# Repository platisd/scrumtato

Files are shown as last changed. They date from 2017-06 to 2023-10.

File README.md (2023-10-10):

# Scrumtato
Scrumtato is an ATtiny85-based gadget to keep overly passionate developers from excessively talking during daily stand-up meetings. The name stems from the combination of [SCRUM](https://en.wikipedia.org/wiki/Scrum_(software_development)) and [Hot Potato](https://en.wikipedia.org/wiki/Hot_potato_(game)).

## About Scrumtato
During our daily stand-up meetings (SCRUM), as we are a team full of talented and passionate developers, we just love to talk too much. This stretches our meeting and keeps us from getting the most out of our working hours. To solve this problem, here comes **Scrumtato: A gadget to make daily stand-ups agile again!**

scrumtatos

## How does it work
Operating the Scrumtato is simple!
1. Press the button when you are ready to talk. You will hear 2 beeps.
2. Start talking. You have to concisely explain what you did since the last meeting and what you are planning to do until the next.
3. If you finish before the time runs out (in which case the Scrumtato will beep and vibrate), press the button again. You will hear 3 beeps.

### More details
The user begins interacting with the Scrumtato by pressing the on-board button and starts talking about all the extraordinary things they got into since the last daily stand-up. This initiates a countdown timer that lasts as long as each team member is supposed to speak. To indicate that half of the remaining time has just been depleted, Scrumtato will beep once. For example, if the total available period for someone to speak is 1 minute, the user will hear beeps on approximately the 30th, 45th, 52nd, 56th, 58th and 59th seconds. As soon as the time is up, a characteristic beep sequence is played and Scrumato vibrates.

In other words, Scrumtato can be considered as a stress ball that... actually stresses you out! If the team member finishes talking in a timely manner, then they merely need to press the button again and a sound sequence that indicates the successful end of a turn is played.

From a technical perspective, since the users should not have to change the battery often, the microcontroller will go to sleep as much as possible. That is between "games" and between beeps or vibrations during the "games". In the former case, the microcontroller is woken up by the button press and in the latter by a watchdog timer.

## Other uses
Scrumtato was initially conceived as a toy for kids (or grown ups, no judging) and particularly, as a way to play Hot Potato. This use case is supported separately from the main one, however their integration into a common program should not be complicated as they share logic and states.

Specifically, the watchdog timer is triggered faster and the buzzer beeps when 5% of the remaining time is depleted, therefore more frequently compared to the stand-up scenario. Additionally, the on-board analog accelerometer is utilized to determine if a player does not pass the ball fast enough. In that case, a faster countdown is initiated and the ball must be passed in a couple of seconds otherwise it "explodes" in the hands of the one that was delaying the game. This increases the suspense and the pace of the game.

The Hot Potato use case is not supported since `rev.3` as the accelerometer was removed. If you want to download that specific version then do `git checkout -b hw_rev.2`.

## Software
The use cases supported by Scrumtato can be found in the [firmware](https://github.com/platisd/scrumtato/tree/master/firmware) directory.

* [Standup Potato](https://github.com/platisd/scrumtato/tree/master/firmware/StandupPotato): The way to make daily stand-ups agile again
* [Hot Potato](https://github.com/platisd/scrumtato/tree/master/firmware/HotPotato): A modern and suspenseful take on the classic Hot Potato game, supported up to `rev.2` hardware.

## Hardware
From a physical perspective, Scrumtato is comprised of a PCB and a 3D-printed case to protect the electronics as well as make passing around easier and more fun.

### PCB
The printed circuit board was designed with [Eagle CAD](https://www.autodesk.com/products/eagle/overview) and the latest `rev. 3` boards were fabricated by [PCBWay](https://www.pcbway.com/project/shareproject/Scrumtato__Make_daily_standups_agile_again__rev_3_.html). Using the above service you can preview your board, as well as any changes you made, before ordering it and have it nicely packaged and delivered to your address in less than a week.

### 3D printed cases
Depending on the how you use Scrumtato, different case should be utilized. When used as a stand-up meeting gadget, it is *probably* not going to be thrown around. Therefore a case from common PLA plastic will work just fine. However, if kids come into the equation a flexible case is strongly suggested, since the gadget will be mishandled and dropped on the floor. After all, this is part of the fun. The flexible version was printed with a [ZYYX+ printer](http://www.zyyx3dprinter.com/), using their proFLEX filament. The PLA version was printed with a [Micro M3D printer](https://printm3d.com/themicro/). The models were sliced with Simplify3D. If you need more information on the specific Simplify3D profiles used, tips on how to print (e.g. when to use support etc) or the source of the models, please contact me.

* [Scrumtato PLA version](https://github.com/platisd/scrumtato/tree/master/physibles/pla) - To be used during the daily stand-up meetings.
* [Scrumtato Flex version](https://github.com/platisd/scrumtato/tree/master/physibles/flex) - To be used as a toy for kids.

### Components
* **[Scrumtato PCB](hardware/)** - You can also [order it from PCBWay](https://www.pcbway.com/project/shareproject/Scrumtato__Make_daily_standups_agile_again__rev_3_.html)
* **Four M3x10 flat head screws** - To mount the board. Longer ones (until M3x40) will also work.
* **Two M3x20 flat head screws** - To keep the upper and bottom part of the case together. Longer ones (until M3x40) will also work. **Only for the toy/flexible version!**
* **CR2032 battery** - To power everything up
* **CR2032 battery holder** - To keep the battery in place. Get the through-hole version.
* **ATtiny85-20PU** - If you only want to use it during stand-up meetings, then an **ATtiny25-20PU** will suffice.
* **DIP-8 socket** - Optional, but will probably make your life easier if you need to remove the microcontroller in order to reprogram it.
* **9mm Buzzer** - They are not the most common but take up less space. I might consider replacing them in the future with something easier to source.
* **22Ω 1206 resistor** - Used for the buzzer. Other low valued resistors will probably work as well.
* **SMD vibrating motor** - To make Scrumtato vibrate. The board is modeled after Sanyo NRS-2574 but all other models that fit the dimensions will work.
* **4-pin tactile switch** - To initiate (or finish occasionally) the game. Get the through-hole version.
* **2-pin angled switch** - As a reset button. Through-hole component.
* **LED 5mm** - Optional and rather unnecessary when using the flexible version since it is not visible.
* **220Ω 1206 resistor** - Optional unless the LED is used.
* **BC547 NPN transistor** - To control the vibration motor.
* **1KΩ 1206 resistor** - To drive the transistor.
* **Two 10KΩ 1206 resistors** - Used as pull ups. One for the microcontroller's reset pin and the other for the tactile switch.
* **Hot Potato toy** - Optionally supported up to hardware `rev.2`
  * **GY-61 accelerometer module** - Based on the ADXL335 chip. Try to get one that has its pins unsoldered.
  * **5-pin angled male header** - To solder on the GY-61 module in order to mount it vertically on the board.
  * **5-pin female header** - So you do not to have to solder the GY-61 module.

## Articles
[Scrumtato: Make daily stand-ups agile again](https://platis.solutions/blog/2017/06/12/scrumtato-make-daily-stand-ups-agile-again/)

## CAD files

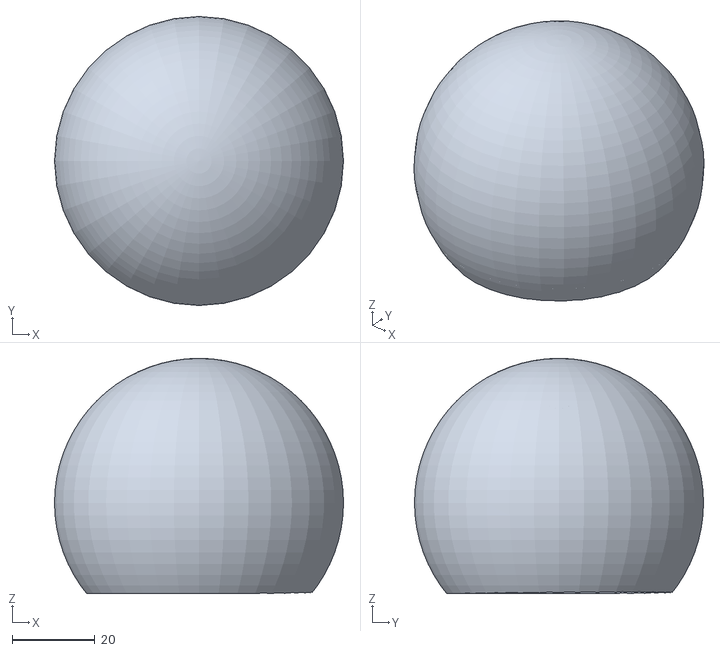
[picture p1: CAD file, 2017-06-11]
physibles/flex/Scrumtato_flex_top.stl
70.0 x 70.0 x 57.0

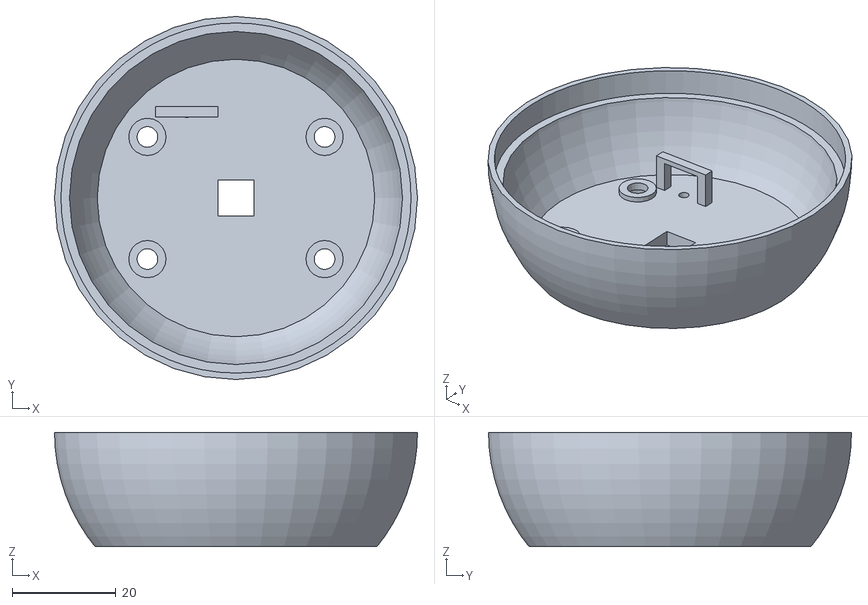
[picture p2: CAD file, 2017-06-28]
physibles/pla/Scrumtato_pla_bottom.stl
70.0 x 70.0 x 22.0

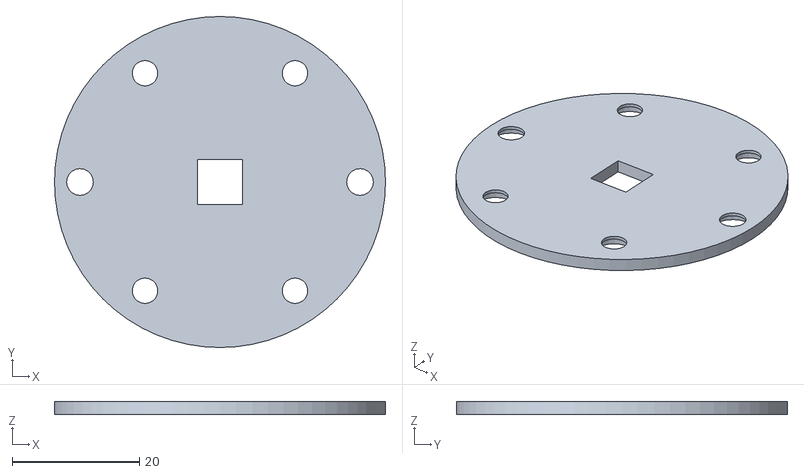
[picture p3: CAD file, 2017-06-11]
physibles/flex/Scrumtato_flex_bottom.stl
52.0 x 52.0 x 2.00

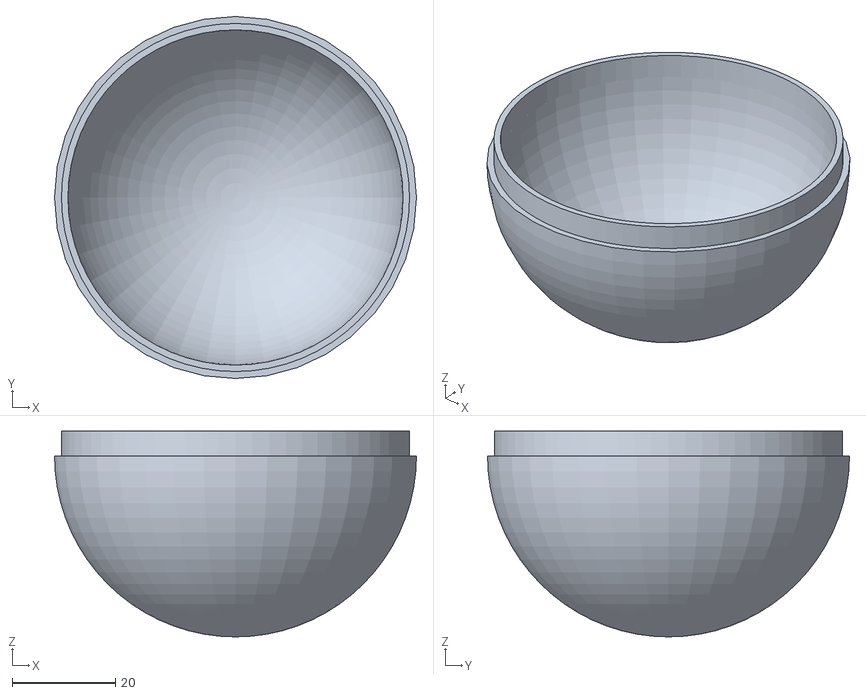
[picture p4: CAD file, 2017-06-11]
physibles/pla/Scrumtato_pla_top.stl
70.0 x 70.0 x 39.8

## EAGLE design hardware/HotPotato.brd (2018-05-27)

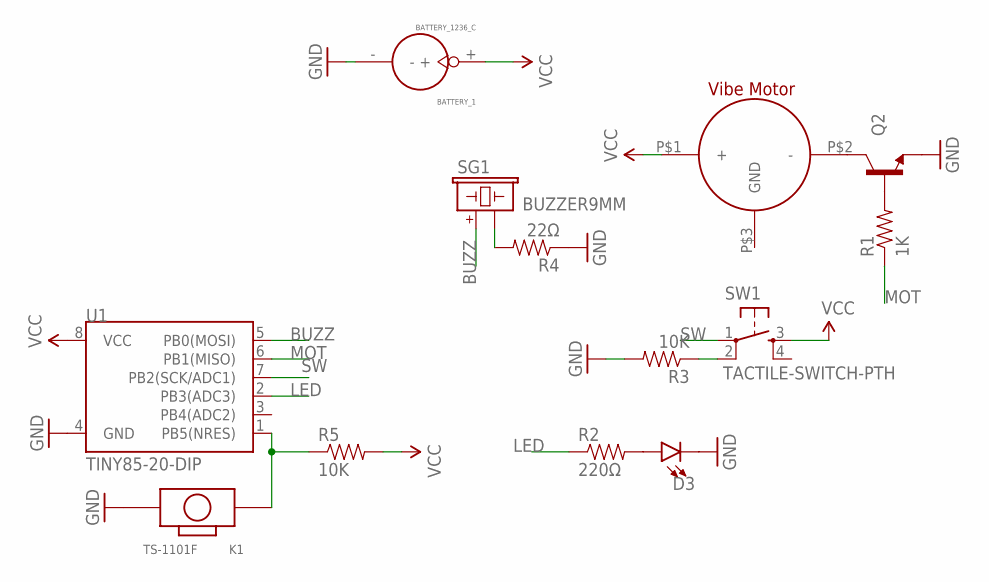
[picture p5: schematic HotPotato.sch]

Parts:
BATTERY_1: BATTERY_1236_C
D3: LED5MM-KIT; LED_5MM-KIT
K1: TS-1101F; SW2-3.4X6.0X3.55MM-90D
M1: SANYO_NRS-2574SMT; SMT
Q2: TRANSISTOR_NPNBC547; TO-92-AMMO
R1: 1K; 1206
R2: 220Ω; 1206
R3, R5: 10K; 1206
R4: 22Ω; 1206
SG1: BUZZER9MM; BUZZER-9MM-PTH_NEW
SW1: TACTILE-SWITCH-PTH; TAC-SWITCH-PTH
U1: TINY85-20-DIP; DIP08

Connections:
BUZZ: SG1.P$1 (1), U1.5 (PB0(MOSI))
GND: BATTERY_1.-, D3.K (C), K1.P$2 (2), Q2.3 (E), R3.2, R4.1, U1.4 (GND)
LED: R2.1, U1.2 (PB3(ADC3))
MOT: R1.1, U1.6 (PB1(MISO))
unnamed: R3.1, SW1.2
unnamed: D3.A, R2.2
unnamed: M1.P$2 (-), Q2.1 (C)
unnamed: Q2.2 (B), R1.2
unnamed: R4.2, SG1.P$2 (2)
unnamed: K1.P$1 (1), R5.1, U1.1 (PB5(NRES))
SW: SW1.1, U1.7 (PB2(SCK/ADC1))
VCC: BATTERY_1.+, M1.P$1 (+), R5.2, SW1.3, U1.8 (VCC)

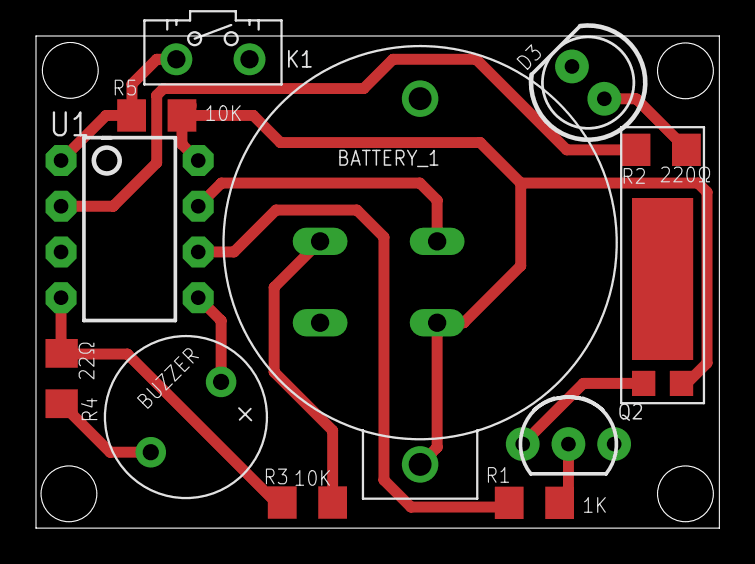
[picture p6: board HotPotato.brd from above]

Board: 2 copper layers, 38.0 x 27.3 mm, 14 parts (1 on the bottom side), 12 nets.

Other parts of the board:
U$1: OSHWLOGO_BACK_0.2

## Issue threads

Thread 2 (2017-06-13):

5mm LED

platisd, 2017-06-13:
As a Scrumtato player I want to have a proper 5mm LED lamp so to make the transparent case light up awesomely.

Closed 2017-06-14.

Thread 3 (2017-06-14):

12mm ⌀ buzzer

platisd, 2017-06-14:
As a Scrumtato fabricator I want to use a buzzer with 12mm diameter so to be able to source them easier as they are more common.

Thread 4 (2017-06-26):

Fix buzzer footprint size and position

platisd, 2017-06-26:
As a Scrumtato manufacturer I want the buzzer footprint to correspond as accurately as possible to the actual buzzer used and not be positioned so close to other components so to be able to expedite the board assembly process.

Closed 2017-10-22.

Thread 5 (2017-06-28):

Transistor to drive the LED and buzzer

platisd, 2017-06-28:
As a Scrumtato player I want to have a transistor driving  the buzzer and the LED so to hear the buzzer loudly and see the LED shine brightly.

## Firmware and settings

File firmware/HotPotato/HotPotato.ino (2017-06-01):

#include <avr/sleep.h>
#include <avr/power.h>
#include <avr/wdt.h>

enum WatchDogTimeout {
  WDT_16ms = 0,
  WDT_32ms,
  WDT_64ms,
  WDT_128ms,
  WDT_250ms,
  WDT_500ms,
  WDT_1sec,
  WDT_2sec,
  WDT_4sec,
  WDT_8sec
};

enum PowerState {
  DEEP_SLEEP,
  GAME
};

const unsigned int BUZZER_PIN = PB0;
const unsigned int MOTOR_PIN = PB1;
const unsigned int BUTTON_PIN = PB2;
const unsigned int ACCELEROMETER_IN = PB3;
const unsigned int ACCELEROMETER_POWER = PB4;

const unsigned long DEFAULT_TURN_DURATION = 60000; // The time in milliseconds that game lasts
unsigned long turnDuration = DEFAULT_TURN_DURATION;
const float beepingRatio = 0.95; // Percentage of the remaining time that should we beep. Controls how often we will beep
unsigned long timeToBeep = (float) DEFAULT_TURN_DURATION * beepingRatio;
volatile bool watchDogBarked = false;
bool watchDogEnabled = false;
const WatchDogTimeout gameWdt = WDT_128ms; // The game interval


WatchDogTimeout currentWdt = gameWdt;
unsigned long elapsedTime = 0; // How much time has elapsed in the running turn in milliseconds

volatile bool buttonPressed = false;

const unsigned long remindBeepDuration = 50; // How long in milliseconds we should beep to "stress" the user

// How long in milliseconds the player has in order to pass the ball after immobility is detected
const unsigned long TIME_TO_PASS_THE_BALL = 2000;
// The threshold (of difference between analogRead values from the accelerometer) over which we register a "movement" (experimentally determined)
// The lower it is, the easier a movement is registered. Or alternatively, the higher it is, the easier immobility is detected.
const unsigned int ACC_THRESHOLD = 80;
// The threshold of the amount of times the analogRead values were below the acceleration threshold.
// Alternatively, how long the ball should stay relatively still in order for the fast count down mode to kick in
// In time, this translates into IMMOBILITY_THRESHOLD * watchdog timeout period
const unsigned int IMMOBILITY_THRESHOLD = 20;
unsigned int prevAccReading = 0; // The last reading by the accelerometer. We start it by 0 but it should not practically make a big differnece
unsigned int immobilityCounter = 0;
bool fastCountdownMode = false;

uint8_t enabledADCSRA = 0; // Will hold the initial ADCSRA value

PowerState currentState = DEEP_SLEEP; // Start with sleep as the initial state

/**
   Vibrate for the specified amount of time (blocking)
   @param duration milliseconds the motor will vibrate
*/
void vibrateFor(unsigned long duration) {
  startVibrating();
  delay(duration);
  stopVibrating();
}

/**
   Utility method that starts the vibrating motor
*/
void startVibrating() {
  digitalWrite(MOTOR_PIN, HIGH);
}

/**
   Utility method that stops the vibrating motor
*/
void stopVibrating() {
  digitalWrite(MOTOR_PIN, LOW);
}

/**
   Ring the buzzer for the specified amount of time (blocking)
   @param duration milliseconds the buzzer will ring
*/
void ringFor(unsigned long duration) {
  startRinging();
  delay(duration);
  stopRinging();
}

/**
   Utility method that starts ringing the buzzer
*/
void startRinging() {
  digitalWrite(BUZZER_PIN, HIGH);
}

/**
   Utility method that stops ringing the buzzer
*/
void stopRinging() {
  digitalWrite(BUZZER_PIN, LOW);
}

/**
   A utility method to derive a watchdog timeout's duration
   @return the amount of milliseconds corresponding to a watchdog timeout
*/
unsigned long getTimeoutDuration() {
  return 1 << (currentWdt + 4);
}

void setupWatchDogTimeoutOneshot(WatchDogTimeout wdt) {
  // Adopted from InsideGadgets (www.insidegadgets.com)
  byte timeoutVal = wdt & 7;
  if (wdt > 7) {
    timeoutVal |= (1 << 5);
  }
  timeoutVal |= (1 << WDCE);

  MCUSR &= ~(1 << WDRF);
  WDTCR |= (1 << WDCE) | (1 << WDE); // Start timed sequence
  WDTCR = timeoutVal;
  WDTCR |= _BV(WDIE);
  wdt_reset();  // pat the dog
  currentWdt = wdt;
}

/**
   Disables the accelerometer by setting the pin that powers it up to LOW
*/
void turnAccelerometerOff() {
  digitalWrite(ACCELEROMETER_POWER, LOW);
}

/**
   Enables the accelerometer by setting the pin that powers it up to HIGH
*/
void turnAccelerometerOn() {
  digitalWrite(ACCELEROMETER_POWER, HIGH);
}

/**
  Watchdog interrupt routine to be triggered when watchdog times out
*/
ISR(WDT_vect) {
  watchDogBarked = true;
  wdt_disable(); // disable watchdog
}

/**
   Change interrupt routine (e.g. when button presses occur)
*/
ISR (PCINT0_vect) {
  // TO-DO: Investigate ways to debounce the button
  if (digitalRead(BUTTON_PIN) == LOW) {
    buttonPressed = true;
  }
}

/**
   Sets up pin change interrupt for PB2
*/
void setupChangeInterrupt() {
  PCMSK |= bit (PCINT2); // want pin D2 (PB2)
  GIFR |= bit (PCIF); // clear any outstanding interrupts
  GIMSK |= bit (PCIE); // enable pin change interrupts
}

/**
   Sets the MCU into a deep sleep state until a change interrupt is triggered
*/
void goToSleep() {
  set_sleep_mode(SLEEP_MODE_PWR_DOWN);
  // Disable ADC when we are in deep sleep state, otherwise have it on
  // We are missing the first analogRead in the game state this way, but we can afford
  // it for the sake of code simplicity
  ADCSRA = currentState == DEEP_SLEEP ? 0 : enabledADCSRA;
  power_all_disable(); // power off ADC, Timer 0 and 1, serial interface
  sleep_enable();
  sleep_cpu(); // Sleep here and wait for the interrupt
  sleep_disable();
  power_all_enable(); // power everything back on
}

void setup() {
  // Set up the I/O pins
  pinMode(BUZZER_PIN, OUTPUT);
  pinMode(MOTOR_PIN, OUTPUT);
  pinMode(BUTTON_PIN, INPUT);
  pinMode(ACCELEROMETER_IN, INPUT);
  pinMode(ACCELEROMETER_POWER, OUTPUT);
  // Log down the value of ADCSRA in order to restore it when necessary
  enabledADCSRA = ADCSRA;
  setupChangeInterrupt();
}

void loop() {
  switch (currentState) {
    case DEEP_SLEEP:
      // Go to deep sleep until an interrupt occurs
      goToSleep();
      // Proceed to the
      if (buttonPressed) {
        // Beep fast twice to indicate the beginning of a game
        ringFor(100);
        delay(100);
        ringFor(100);
        currentState = GAME;
        buttonPressed = false;
        turnAccelerometerOn();
      }
      break;
    case GAME:
      // If watchdog is not enabled, then we either just arrived from SLEEP state
      // or from a watchdog bark. Therefore we need to set another watchdog timer.
      if (!watchDogEnabled) {
        // Set up watchdog to be triggered (once) after the specified time
        setupWatchDogTimeoutOneshot(gameWdt);
        watchDogEnabled = true;
      }
      // Go to deep sleep until an interrupt occurs
      goToSleep();
      // We might have gone out of sleep due to another interrupt (i.e. the switch)
      // So make sure that we know what we are doing depending on who interrupted our sleep
      if (watchDogBarked) {
        watchDogBarked = false;
        watchDogEnabled = false;
        elapsedTime += getTimeoutDuration();
        unsigned long remainingTime = turnDuration - elapsedTime;
        /* --- Main game logic --- */
        if (elapsedTime >= turnDuration) { // End of game
          // Play a sound and vibration sequence to indicate the end of a game due to timeout
          startVibrating();
          ringFor(50);
          delay(50);
          ringFor(50);
          delay(50);
          ringFor(800);
          stopVibrating();
          currentState = DEEP_SLEEP;
          elapsedTime = 0;
          turnDuration = DEFAULT_TURN_DURATION; // Reset the turn duration that might have been changed
          timeToBeep = turnDuration * beepingRatio; // reset the remaining time since the turn is over
          immobilityCounter = 0;
          fastCountdownMode = false;
          turnAccelerometerOff();
        } else if (remainingTime <= timeToBeep) { // Time to beep
          // Ring when we reach half of the remaining time available
          ringFor(remindBeepDuration);
          elapsedTime += remindBeepDuration; // Add the time we spent ringing
          timeToBeep *= beepingRatio;
        }
        // We need to detect if a player is holding the ball for too long in order to start a fast countdown
        // If the ball is not moved during the designated time to pass the ball, then the game ends prematurely
        unsigned int currentAccReading = analogRead(ACCELEROMETER_IN);
        int accDelta = currentAccReading - prevAccReading;
        prevAccReading = currentAccReading;
        // If the ball has not been moved enough (i.e. thrown)
        if (abs(accDelta) <= ACC_THRESHOLD) {
          // Register a touch and check if the ball has been held for too long
          if (++immobilityCounter >= IMMOBILITY_THRESHOLD) {
            // If we are not already in fast countdown mode, start the fast countdown
            if (!fastCountdownMode) {
              unsigned long decreasedTurnDuration = elapsedTime + TIME_TO_PASS_THE_BALL;
              // Go into fast countodown only if the decreased turn duration is actually after when the game
              // is supposed to finish. In that case do not adjust the time so the users do not cheat by prolonging the game
              if (decreasedTurnDuration <= DEFAULT_TURN_DURATION) { // If the turn duration is actually decreased and not extended
                turnDuration = decreasedTurnDuration;
                fastCountdownMode = true;
              }
            }
          }
        } else {
          // Restore the counter if there was a movement but only restore the duration and time to beep
          // if we just were in fast countdown mode
          immobilityCounter = 0;
          if (fastCountdownMode) {
            turnDuration = DEFAULT_TURN_DURATION;
            timeToBeep = (turnDuration - elapsedTime) * beepingRatio;
            fastCountdownMode = false;
          }
        }
      }
      buttonPressed = false;
      break;
    default:
      break;
  }
}

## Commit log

2017-05-23 Rev. 0 of board
    Known problems:
    * Buzzer footprint needs to have the pins slightly further from each other
    [HotPotato.brd, HotPotato.sch]
2017-05-23 Initial commit with deep sleep and watchdog timer
2017-05-27 Add standup potato firmware
    A basic version of the scrumtato (Hot potato for daily standup meetings).
    TO-DO: Accelerometer currently not used. Decide whether to use it or remove
    completely from code.
2017-05-27 Register button pressed on button up
    WIP anyway, this firmware will drastically change
2017-05-28 Hot potato game
    For the time being without using the accelerometer
2017-05-30 Adding accelerometer detection of movement
    The ball can now detect if the user is holding it for too long
    in their hands. If that happens, we start counting down faster so to
    "explode" in case the ball is not passed.
    [HotPotato.ino]
2017-06-11 Add Scrumtato's 3D models
    [Scrumtato_flex_bottom.stl, Scrumtato_flex_top.stl, Scrumtato_pla_bottom.stl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]
2017-06-14 Change LED package to 5mm
    Fixes #2
    [HotPotato.brd, HotPotato.sch]
2017-06-14 Add reset button
    Fixes #1
    [HotPotato.brd, HotPotato.sch]
2017-06-14 Change board name and board revision
    [HotPotato.brd]
2017-06-14 Small mainly commodity fixes
    Changing orientation of D3, placement of R4, SW1 part number placement
    [HotPotato.brd]
2017-06-27 Update components according to rev.1 board
2017-06-28 Add rev. 1 bottom part of the PLA version
    Adds a pin-hole for reset button and a small holder to stop the buttom from bending upwards when pressed
    [Scrumtato_pla_bottom.stl]
2017-06-29 Add links to purchase board
    From OSHPark and Seeedstudio for rev. 1
2017-07-04 Add PCB fab info
2017-10-22 Increase distance between buzzer poles
    Fixes #4
    [HotPotato.brd, HotPotato.sch]
2018-05-27 Remove accelerometer header and set dedicated LED pin
    [hw rev. 3]
    Since the Hot Potato (game) use case was deemed less significant
    hardware support for it was removed in order to leave more space
    for the common components. This also enabled us to use a dedicated
    pin for the LED which was previously routed in parallel with the
    buzzer. This should enable better control over the hardware and
    (theoretically) more current to be supplied to the LED and the
    buzzer.
    [HotPotato.brd, HotPotato.sch]

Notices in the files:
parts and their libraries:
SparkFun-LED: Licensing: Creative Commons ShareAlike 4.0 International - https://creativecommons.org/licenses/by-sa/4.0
